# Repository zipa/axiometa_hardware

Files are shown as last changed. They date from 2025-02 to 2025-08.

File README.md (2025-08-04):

# BrodBoost-C

BrodBoost-C is a breadboard power supply that connects via USB Type-C and delivers selectable 5 V and 3.3 V outputs. Its compact design minimizes the need for additional wiring, cable modifications, or bulky bench supplies. The device features independent voltage adjustments for each rail, a manual on/off switch, an LED indicator, and built-in fuse protection, making it a practical solution for projects using standard 2.54 mm breadboards. The 3.3 V regulator is based on the TPS63001, a switching step-down DC-DC converter.

BrodBoost-C is a project of Axiometa, information available on the [website](https://www.axiometa.io/products/brodboost-c-breadboard-power-supply).

Breadboost-C_169_WHITE

# Overview
DEVICE DETAILS

# Compatibility
DIMESNIONS

# Voltage Selection
Both voltage rails can be independently selected or simultaneously set to 5.0 V or 3.3 V by moving around the jumper cap. Although the jumper cap design has received mixed opinions, it is implemented here as a safety feature and to be cautios of BOM. The design requires deliberate jumper cap movement, which helps prevent accidental voltage changes from 3.3 V to 5.0 V that might occur if a switch were used.

vselect

# Schematic
A USB-C receptacle accepts a USB-C cable. The power rails include a series ferrite bead for noise suppression, a 1 A polyfuse for short-circuit protection, and two decoupling capacitors (1 µF and 100 nF). The 5 V from the USB-C port is configured by pulling the CC1 and CC2 lines to ground through 5.1 kΩ resistors.

The power then flows through a series power switch and a parallel red power LED. A step-down conversion from 5 V to 3.3 V is performed using the TPS63001, a switching step-down DC-DC converter.

Both voltage outputs (5.0 V and 3.3 V) are routed to two 1×3 2.54 mm headers, where the middle pin is the selected net and either side may be used for short-circuiting the respective rail. Additionally, a separate header provides access to 5 V, 3.3 V, ground, and USB data lines for debugging, testing, or experimenting with USB data.

schematicbbc

# PCB Design
BrodBoost-C is a two-layer PCB measuring 11.4 mm by 54.0 mm, designed to maximize trace width and optimize the switching regulator's ground return path. This layout comfortably supports the nominal device current of approximately 1 A.

PCB_Layout

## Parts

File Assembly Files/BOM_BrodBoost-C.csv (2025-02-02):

Designator | Footprint | Quantity | Value | LCSC Part #
C1 | 402 | 1 | 1uF | C52923
C2, C5 | 402 | 2 | 100nF | C1525
C3, C4, C6 | 603 | 3 | 10uF | C19702
C7 | 603 | 1 | 100nF | C14663
D1 | 603 | 1 | C2286 | C2286
F1 | 1812 | 1 | BSMD1812-110-24V | C883149
FB1 | 805 | 1 | FerriteBead | C1017
J1, J2 | PinHeader_2x03_P2.54mm_Vertical_SMD | 2 | Conn_02x02_Counter_Clockwise | C3294461
J3, J4 | PinHeader_1x03_P2.54mm_Vertical | 2 | Select | C5360899
J6 | PinHeader_1x05_P2.54mm_Horizontal | 1 | Breakout | DNP
L1 | L_Sunlord_SWPA4012S | 1 | 2.2uH | C167776
P1 | USB_C_Receptacle_HRO_TYPE-C-31-M-12 | 1 | USB Type C | C2927038
R1 | 402 | 1 | 2k | C4109
R2 | 402 | 1 | 100 | C25076
R3, R4 | 402 | 2 | 5.1k | C25905
U2 | Switch_Side | 1 | Side_Switch_SMD | C2911519
U4 | Texas_DRC0010J_ThermalVias | 1 | TPS63001 | C28060

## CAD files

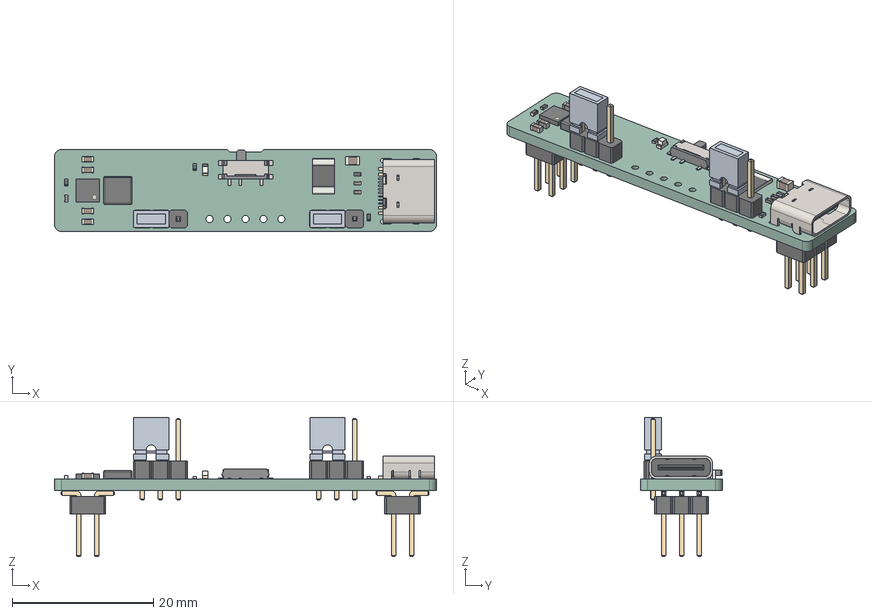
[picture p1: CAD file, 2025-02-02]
Schematics, 3D Model/Step_BrodBoost-C.step
54.0 x 11.6 x 19.7 mm
C_0603_1608Metric x 4
PinHeader_1x03_P254mm_Vertical x 2
M7580_ASM x 2
CQ assembly
R_0402_1005Metric x 4
C_0805_2012Metric
Fuse_0805_2012Metric
C_0402_1005Metric x 3
PCM12SMTR
VSON_8_33x33mm_Pitch065mm_NexFET
LED_0603_1608Metric
Type-C 16P
PinHeader_2x03_P254mm_Vertical_SMD x 2
BrodBoost-C_PCB

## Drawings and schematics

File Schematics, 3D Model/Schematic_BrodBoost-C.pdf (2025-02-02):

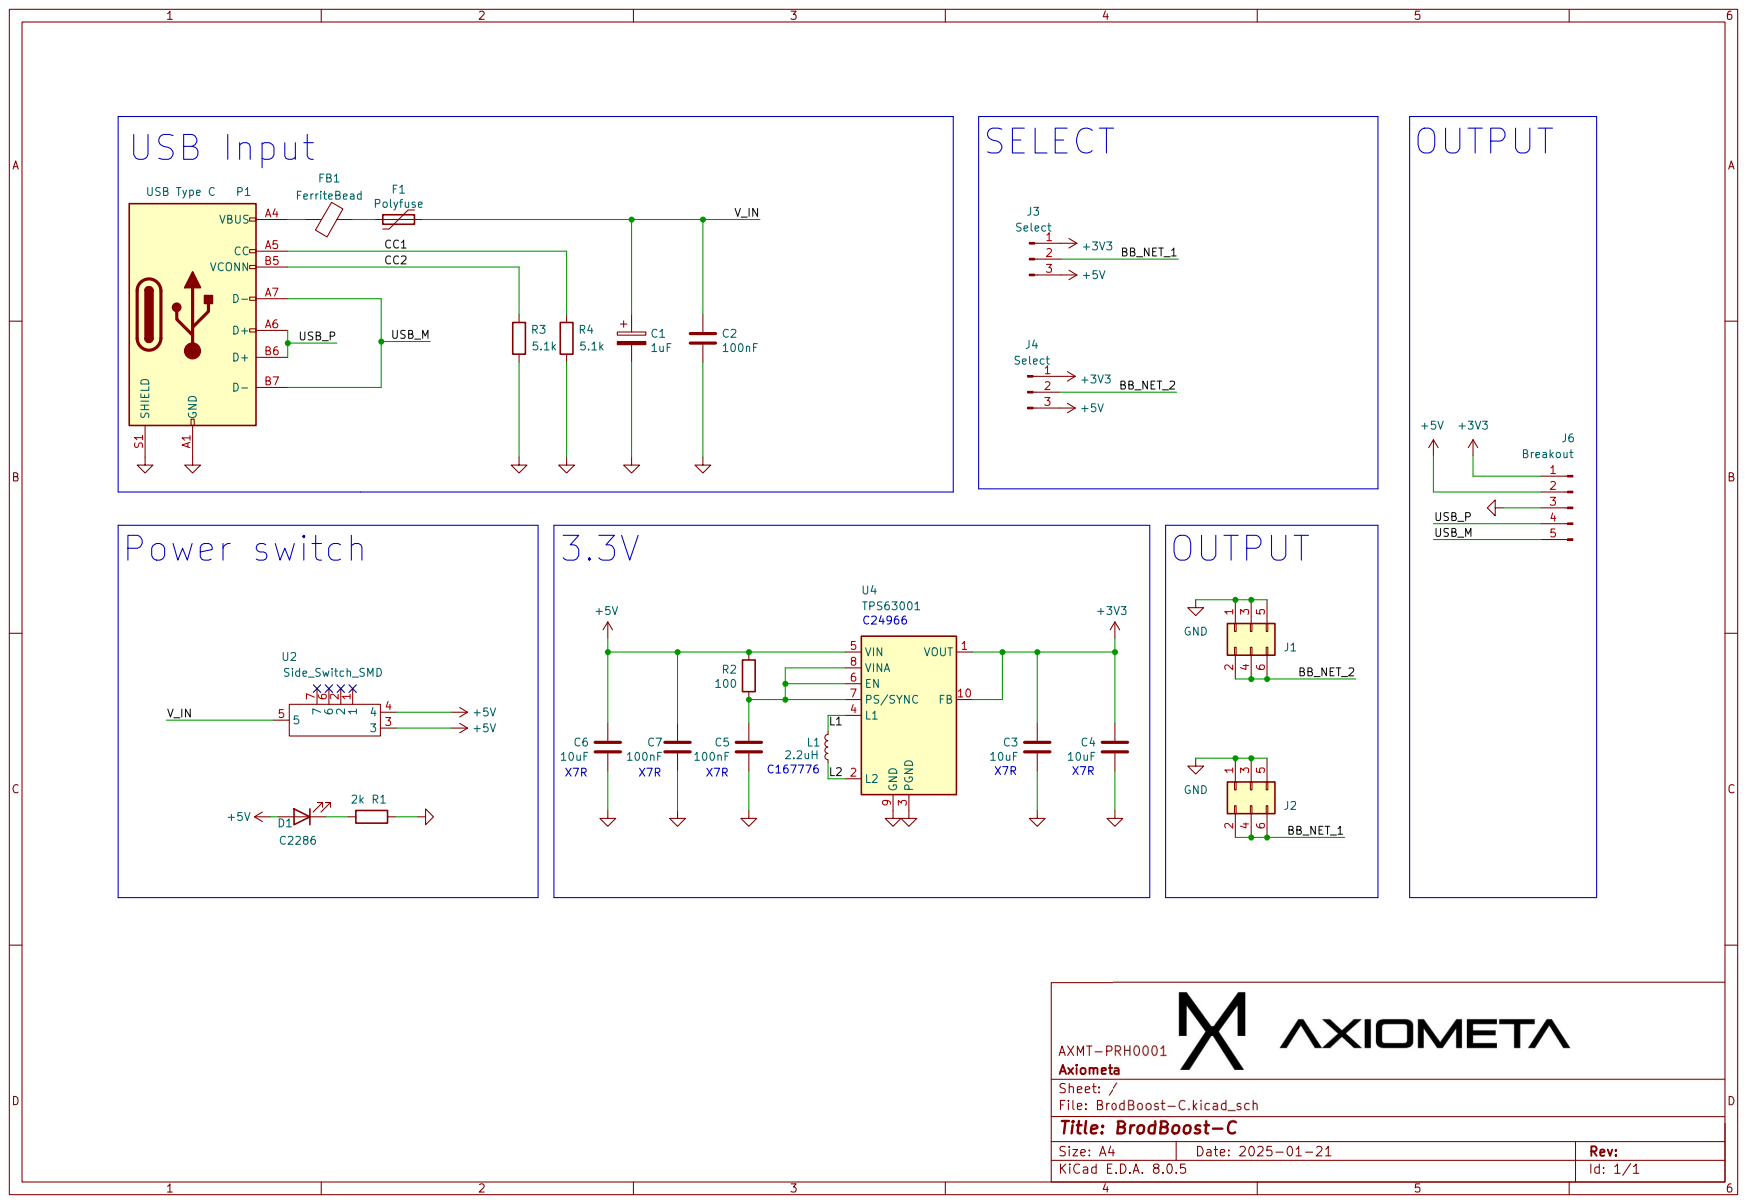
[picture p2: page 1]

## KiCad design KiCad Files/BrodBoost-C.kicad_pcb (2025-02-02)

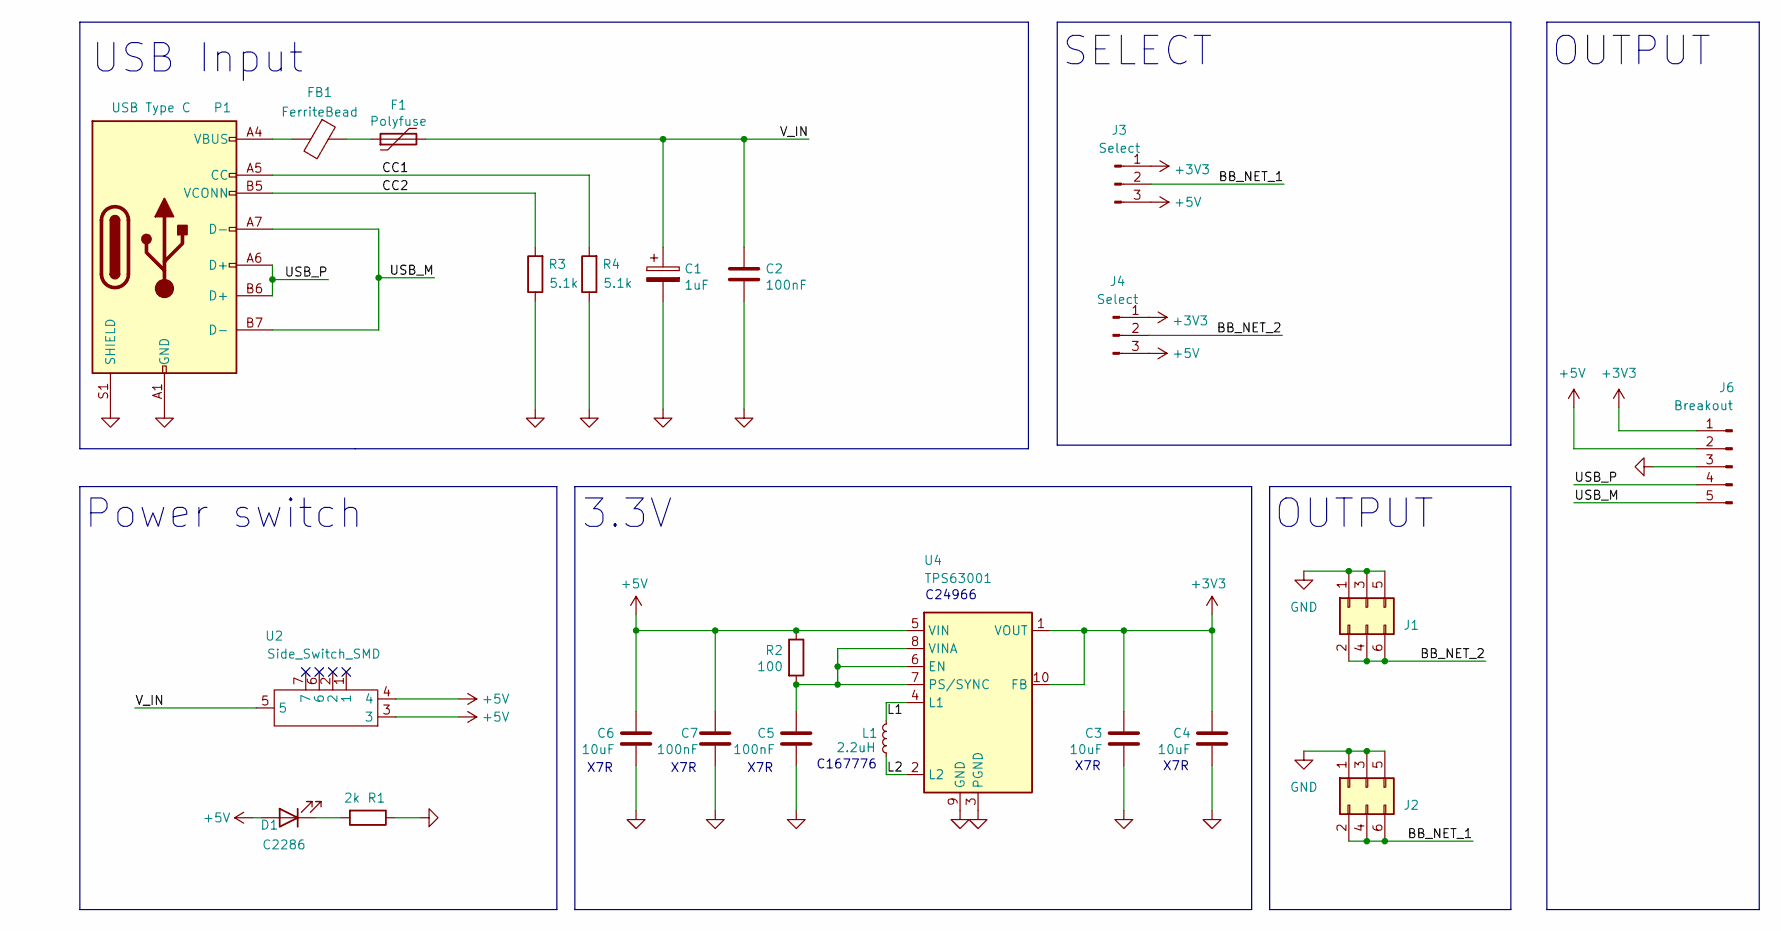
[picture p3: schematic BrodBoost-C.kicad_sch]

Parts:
C1: 1uF; C_0402_1005Metric
C2, C5: 100nF; C_0402_1005Metric; JLCPCB C14663
C3, C4, C6: 10uF; C_0603_1608Metric; JLCPCB C14663
C7: 100nF; C_0603_1608Metric; JLCPCB C14663
D1: C2286; LED_0603_1608Metric
F1: Polyfuse; Fuse_1812_4532Metric_Pad1.30x3.40mm_HandSolder
FB1: FerriteBead; C_0805_2012Metric
J1, J2: Conn_02x02_Counter_Clockwise; PinHeader_2x03_P2.54mm_Vertical_SMD
J3, J4: Select; PinHeader_1x03_P2.54mm_Vertical
J6: Breakout
L1: 2.2uH; L_Sunlord_SWPA4012S
P1: USB Type C; USB_C_Receptacle_HRO_TYPE-C-31-M-12
R1: 2k; R_0402_1005Metric
R2: 100; R_0402_1005Metric
R3, R4: 5.1k; R_0402_1005Metric
U2: Side_Switch_SMD; Switch_Side
U4: TPS63001; Texas_DRC0010J_ThermalVias

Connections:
+3V3: C3.1, C4.1, J3.1, J4.1, J6.1, U4.1 (VOUT), U4.10 (FB)
+5V: C6.1, C7.1, D1.2 (A), J3.3, J4.3, J6.2, R2.1, U2.3, U2.4, U4.5 (VIN)
/BB_NET_1: J2.2, J2.4, J2.6, J3.2
/BB_NET_2: J1.2, J1.4, J1.6, J4.2
/CC1: P1.A5 (CC), R4.2
/CC2: P1.B5 (VCONN), R3.2
/L1: L1.2, U4.4 (L1)
/L2: L1.1, U4.2 (L2)
/USB_M: J6.5, P1.A7 (D-), P1.B7 (D-)
/USB_P: J6.4, P1.A6 (D+), P1.B6 (D+)
/V_IN: C1.1, C2.1, F1.2, U2.5
GND: C1.2, C2.2, C3.2, C4.2, C5.2, C6.2, C7.2, J1.1, J1.3, J1.5, J2.1, J2.3, J2.5, J6.3, P1.A1 (GND), P1.A12 (GND), P1.B1 (GND), P1.B12 (GND), P1.S1 (SHIELD), R1.1, R3.1, R4.1, U4.3 (PGND), U4.9 (GND), U4.11 (PGND)
unnamed: D1.1 (K), R1.2
unnamed: F1.1, FB1.1
unnamed: FB1.2, P1.A4 (VBUS), P1.A9 (VBUS), P1.B4 (VBUS), P1.B9 (VBUS)
unnamed: C5.1, R2.2, U4.6 (EN), U4.7 (PS/SYNC), U4.8 (VINA)

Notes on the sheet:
OUTPUT
X7R
Power switch
C167776
3.3V
USB Input
C24966
SELECT

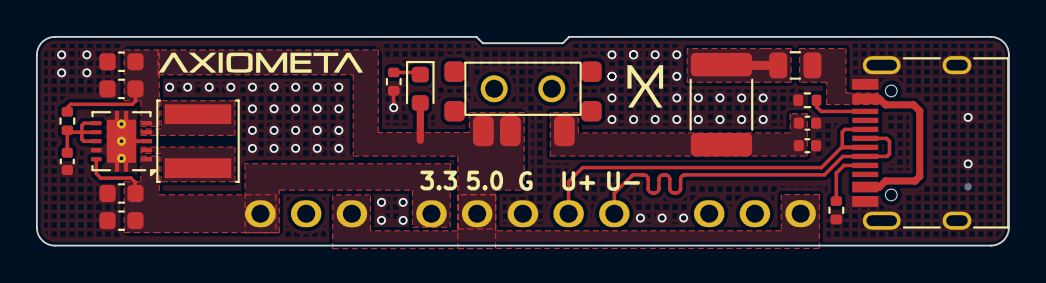
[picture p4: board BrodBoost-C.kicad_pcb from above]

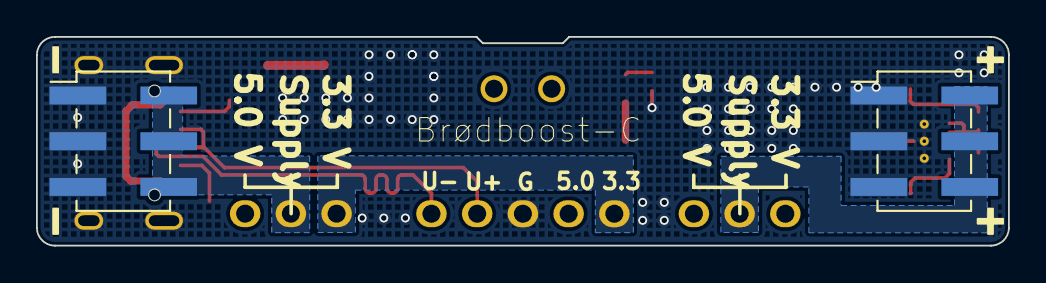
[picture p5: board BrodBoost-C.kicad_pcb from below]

Board: 2 copper layers, 54.0 x 11.6 mm, 23 parts (2 on the bottom side), 16 nets.

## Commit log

2024-12-29 Axiometa Spark 2
    [Axiometa_Spark2_V2.0.kicad_pcb, Axiometa_Spark2_V2.0.kicad_sch, MCU.kicad_sch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]
2025-01-04 deleted old hierarachy
    [Axiometa_Spark2_V2.0.kicad_pcb, Axiometa_Spark2_V2.0.kicad_sch, MCU.kicad_sch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]
2025-01-04 moved files to a folder
    [Breadboost-C.kicad_pcb, Breadboost-C.kicad_sch]
2025-01-04 name changes
    [Breadboost-C.kicad_pcb, Breadboost-C.kicad_sch]
2025-01-04 added breadboost-c
    [Breadboost-C.kicad_pcb, Breadboost-C.kicad_sch, bom.csv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]
2025-01-04 name chnages
    [Breadboost-C.kicad_pcb, Breadboost-C.kicad_sch, bom.csv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]
2025-02-02 added assembly files
    [BOM_BrodBoost-C.csv, POS_BrodBoost-C.csv, STP_BrodBoost-C.step]
2025-02-02 added kicad project
    [BrodBoost-C.kicad_pcb, BrodBoost-C.kicad_sch]
2025-02-02 added quick access schematic
2025-02-02 added schematics and 3d model
    [STP_BrodBoost-C.step]
